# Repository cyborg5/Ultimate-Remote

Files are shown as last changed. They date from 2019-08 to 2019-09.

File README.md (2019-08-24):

# Assistive Technology Ultimate Remote
## This assistive technology device combines infrared and Bluetooth control that can be operated with just 2 or 3 AT switches

In my lifelong struggle to deal with my neuromuscular disease Spinal Muscular Atrophy (SMA), I've built a variety of assistive technology devices. But the most powerful and useful device I've built is my "Ultimate Remote". It combines infrared control of TV, DVR/cable box, DVD/Blu-ray players as well as IR mouse and keyboard emulation. It also includes a Bluetooth device for iOS switch control of my iPhone or iPad. The first version of this device was created in the late 2015 and it has evolved through several versions. It's always been my intent to document the device so that other disabled people can take advantage of what I've developed. Because it was an evolving design I've not documented it until now. However I've cleaned up the code, redesigned the 3D printed enclosure and it's finally ready to share with the world.

This repository contains all of the files will need to build this device.

A complete tutorial on how to build and operate it can be found on the Adafruit Learning System at [https://learn.adafruit.com/building-the-assistive-technology-ultimate-remote/](https://learn.adafruit.com/building-the-assistive-technology-ultimate-remote/) coming soon.

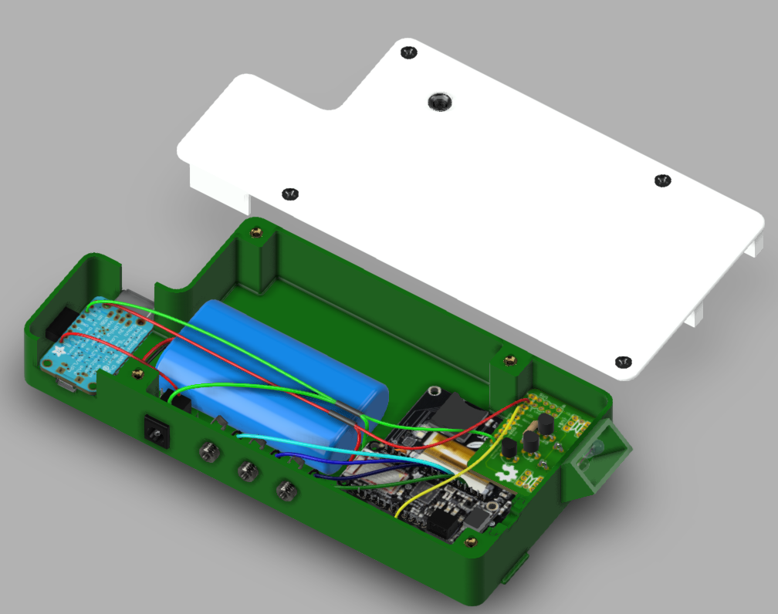
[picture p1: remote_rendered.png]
rendered_image


Included in this repository
 - STL files  -- 3D printer files for the case
    - M3 screws with brass inserts -- files for case held together with M3 screws
      - case_m3.stl
      - lid_with_hole_m3.stl
      - lid_without_hole_m3.stl
    - 6-20 screws into plastic -- files for case held together by #6-20 sheel metal screws
      - case_6-20.stl
      - lid_with_hole_6-20.stl
      - lid_without_hole_6-20.stl
    - dongle_case.stl  --  3D printer file for dongle case
    - dongle_lid.stl  -- 3D printer file for dongle lid
    - door.stl  --  3D printer file for USB cover door
    - guard.stl -- 3D printer file for LED guard
 - ultimate_remote  -- source code for the remote
 - trinket_dongle  -- source code for keyboard and mouse emulator dongle
 - Ultimate Remote 2.3.f3z   -- Fusion 360 model for case and components

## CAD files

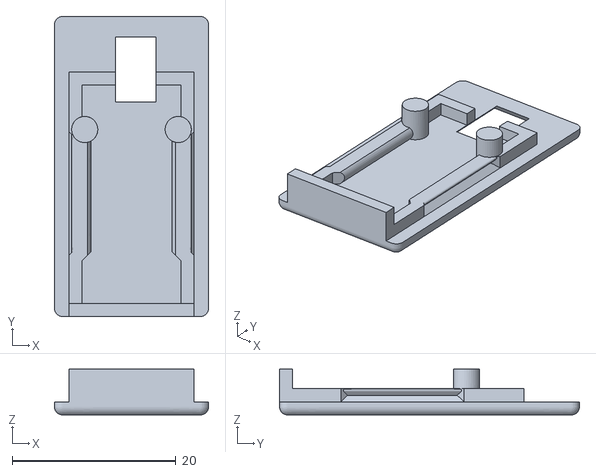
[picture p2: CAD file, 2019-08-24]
STL files/dongle_lid.stl
18.8 x 36.7 x 5.60

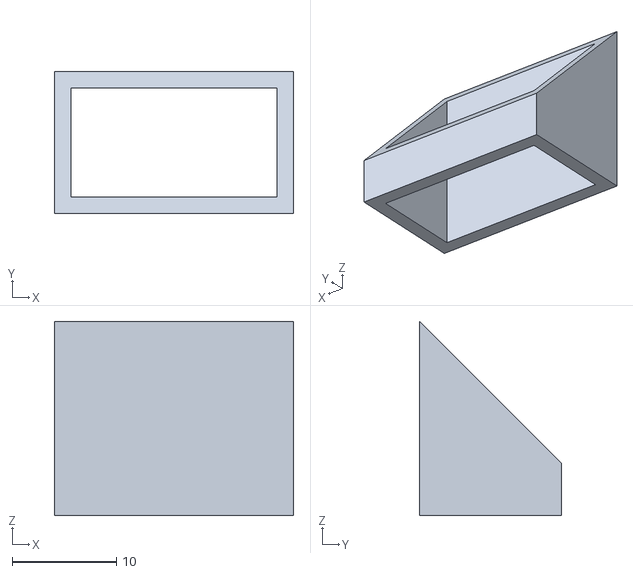
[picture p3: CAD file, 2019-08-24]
STL files/guard.stl
22.9 x 13.6 x 18.6

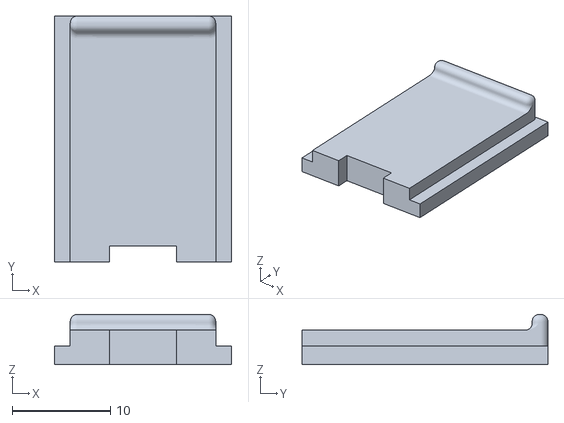
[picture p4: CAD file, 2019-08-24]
STL files/door.stl
18.0 x 25.0 x 5.10

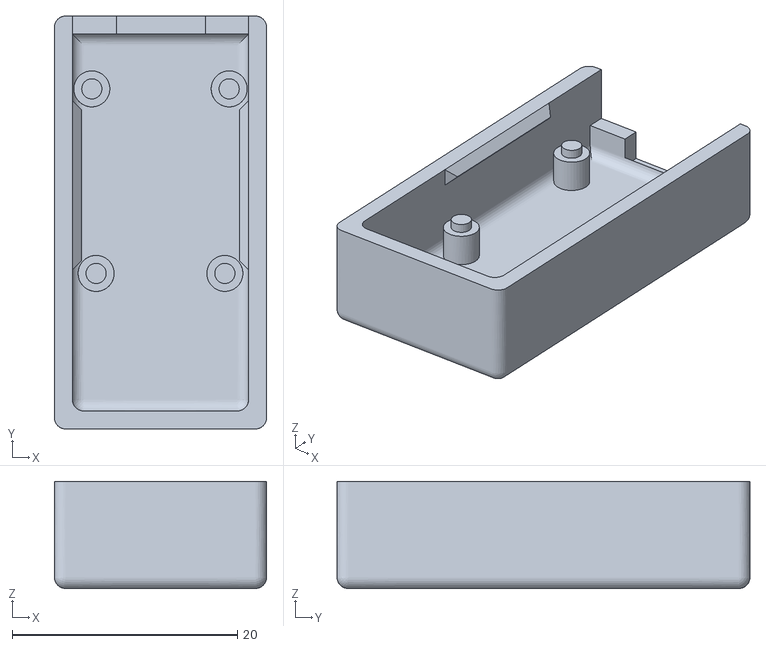
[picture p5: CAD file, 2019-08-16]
STL files/dongle_case.stl
18.8 x 36.7 x 9.50

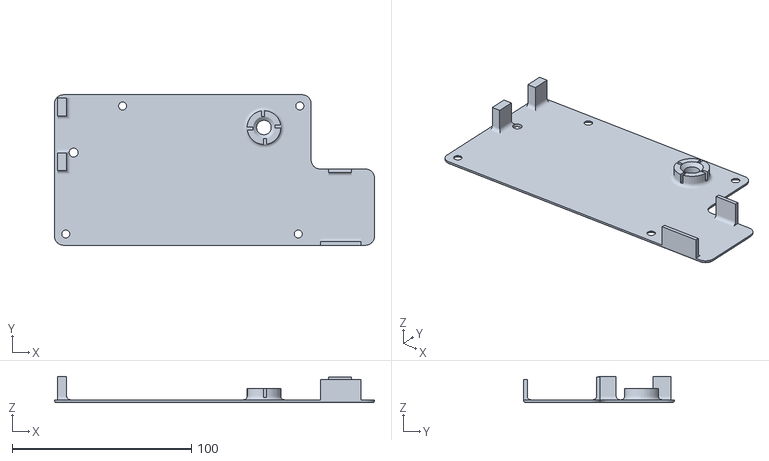
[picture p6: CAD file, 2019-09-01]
STL files/6-20 screws into plastic/lid_with_hole_6-20.stl
178.4 x 84.0 x 14.6

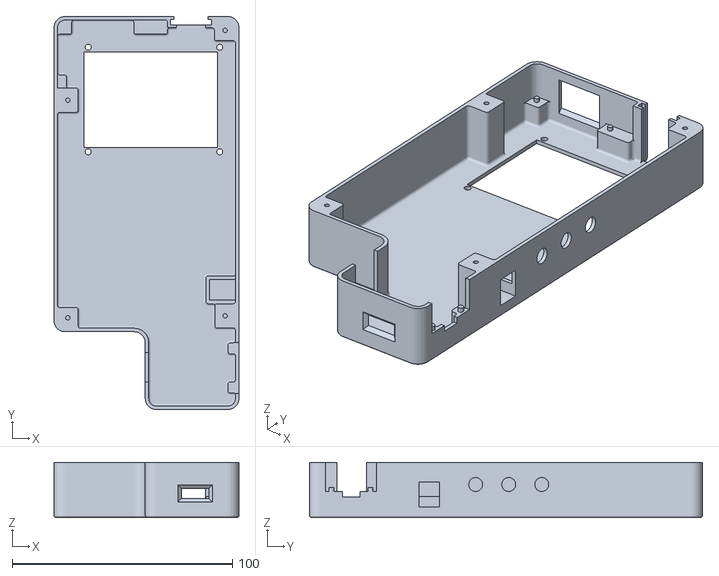
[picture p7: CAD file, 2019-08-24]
STL files/6-20 screws into plastic/case_6-20.stl
84.0 x 178.4 x 25.0

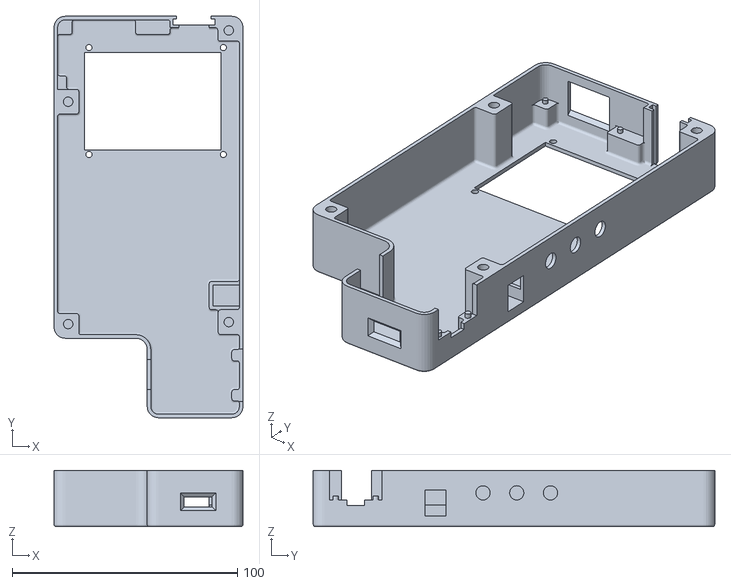
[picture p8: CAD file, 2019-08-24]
STL files/M3 screws with brass inserts/case_m3.stl
84.0 x 178.4 x 25.0

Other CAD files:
STL files/M3 screws with brass inserts/lid_with_hole_m3.stl
STL files/6-20 screws into plastic/lid_without_hole_6-20.stl
STL files/M3 screws with brass inserts/lid_without_hole_m3.stl

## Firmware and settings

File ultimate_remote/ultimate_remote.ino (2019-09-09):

/*
 * Code for "Ultimate Remote" which handles transmission of IR codes for TV, cable, Blu-ray etc.
 * as well as a Bluetooth mode to connect to an iOS device such as iPad or iPhone to use Bluetooth
 * switch control features
 * 
 * Designed for use with 3 switches that are "Left", "Select", and "Right". See "my_inputs.h" for details.
 * 
 * All files in his package are open source under Creative Commons CC BY-SA
 * 
 * Developed by Chris Young cy_borg5@cyborg5.com
 * http://tech.cyborg5.com/
 * 
 */

#define MY_DEBUG 0
#define USE_BLE 1
#define USE_TOUCHSCREEN 1

/***************************
 * Feather TFT
 ***************************/
#include <Wire.h>
#include <Adafruit_ILI9341.h>
//Assumes Feather M0 or M4 or other compatible
   #define STMPE_CS 6
   #define TFT_CS   9
   #define TFT_DC   10
   #define SD_CS    5
#include <Fonts/FreeMono18pt7b.h>
#include "SymbolMono18pt7b.h"
Adafruit_ILI9341 display= Adafruit_ILI9341(TFT_CS, TFT_DC);
#define BACKLIGHT_PIN  13

void Message(const char msg[],uint16_t Duration) {
#if MY_DEBUG
  Serial.println(msg);
#endif
  display.fillRect(0,0,240,50,ILI9341_BLACK); 
  display.setCursor(0,0);
  display.println(msg); 
  delay(Duration);
}

void error(const char err[]) {
  Message(err, 2000);
  //while (1);
}

/***************************
 * Global Variables
 ***************************/

//Row and Col are the current position of the cursor.
//pRow and pCol are the previous position of the cursor.
uint8_t Row, pRow, Col, pCol; 

//The number of rows in the current page.
uint8_t Num_Rows;

//The width of the current page.
uint8_t Page_Width;

//Status of the display backlight. Turns itself off after certain amount of time.
//Also the "select" command doesn't work when the display is off just in case.
bool Backlight_Status;  

//"Page" is the currently displayed page. "Old_Page" remembers what page we were on
// when we switched to Bluetooth mode so that when we exit Bluetooth we will go back to the
// page that we were on.
uint8_t Page, Old_Page;

//Timestamp of the last time we updated the screen i.e. processed a command
uint32_t Time_of_Last_Update;

//The most recent results from Read_Buttons()
uint8_t Current_Buttons;

//Each command consists of a character display, the 32-bit IR value to be
// transmitted, the protocol number, and a special flag hich alternatively may indicate
// the number of bits.
typedef struct cmnd {
  uint8_t Glyph;    //The character to be displayed
  int32_t Value;    //string of bits to be transmitted or page number two change to
                    // if Special == SPL_CHANGE_PAGE
  uint8_t Protocol; //Sony, NEC etc.
  uint8_t Special;  //special handling flag or number of bits
} cmnd_t;

//The current command that the cursor rests on.
struct cmnd Current;

//The full keyboard screen PAGE_KB needs special handling so that it properly displays
// shifted characters. The flag kb_shift is true if we have toggled on Shift.
// This array maps on shifted display glyphs to their shifted value.
bool kb_shift;
uint8_t Shifted [] = {
          0,  1,  2,  3,  4,  5,  6,  7,  8,  9,
         10, 11, 12, 13, 14, 15, 16, 17, 18, 19,
         20, 21, 22, 23, 24, 25, 26, 27, 28, 29,
         //      sp   !   "   #   $   %   &   ' 
         30, 31, 32, 33, 34, 35, 36, 37, 38,'"',
       // (   )   *   +   ,   -   .   /   0   1  
         40, 41, 42, 43,'<','_','>','?',')','!',
       // 2   3   4   5   6   7   8   9   ;   ;  
         '@','#','$','%','^','&','*','(',':',59,
         60, 61, 62, 63, 64, 65, 66, 67, 68, 69,
         70, 71, 72, 73, 74, 75, 76, 77, 78, 79,
         80, 81, 82, 83, 84, 85, 86, 87, 88, 89,
         90,'{','|','}', 94, 95,'~','A','B','C',
        'D','E','F','G','H','I','J','K','L','M',
        'N','O','P','Q','R','S','T','U','V','W',
        'X','Y','Z',123,124,125,126,127};
  
//Types of special commands stored in Current.Special
#define SPL_QUIT    1
#define SPL_REC     2
#define SPL_GOTO_RIGHT 3
#define SPL_GOTO_DOWN 4
#define SPL_GOTO_TVAR 5
#define SPL_CHANGE_PAGE 6
#define SPL_HOLD 7
#define SPL_KB_SHIFT 8

//The maximum number of commands in a display column
#define COL_MAX   14

//The number of minutes of inactivity before the backlight turns off
#define LIGHT_TIMEOUT 5ul

//Return codes from Read_Buttons(). 
#define PUSHED_NONE     0
#define PUSHED_LEFT     1
#define PUSHED_SELECT   2
#define PUSHED_RIGHT    4
#define PUSHED_DOWN     (PUSHED_RIGHT + PUSHED_SELECT)
#define PUSHED_UP       (PUSHED_LEFT  + PUSHED_SELECT)
#define PUSHED_ALL      (PUSHED_LEFT  + PUSHED_SELECT + PUSHED_RIGHT)
//Not used but here just for illustrative purposes
#define PUSHED_SPLIT    (PUSHED_RIGHT + PUSHED_LEFT)

//Specifies the pages of commands to be displayed
#include "my_pages.h"

//Handles touchscreen input
#include "my_touch.h"

//Hardware specific routines to read the buttons
#include "my_inputs.h"

//All of my code for handling BLE switch control
#include "my_ble_code.h"

IRsend mysend; //Infrared sending object

//Turns the backlight on or off depending on flag.
void setBacklight(bool Flag) {
  Backlight_Status = Flag;
  if(Backlight_Status) {
    digitalWrite(BACKLIGHT_PIN, HIGH);
    //Record the time so that we know when to turn off the backlight for being idle too long
    Time_of_Last_Update = millis(); 
  } else {
    #if(MY_DEBUG)
      Serial.println("Backlight off");
    #endif
    digitalWrite(BACKLIGHT_PIN, LOW);    
  }
}

//Displays an "are you sure?" message on the display
// user must press "Right" button for yes. Any other press
// or a timeout results in no.
bool Are_You_Sure() {
  bool Result=false;
  unsigned long Amount = millis();    //Start the timeout clock
  display.fillScreen(ILI9341_BLACK);
  display.setCursor(0, 0); display.print(F("R U sure?"));
  display.setCursor(0, 25); display.print(F("Press Right"));
  display.setCursor(0, 50); display.print(F("For Yes"));
  do {    //Read the buttons until one is pressed for time runs out
    if (Read_Buttons() ) break;
  } while ( (millis() - Amount) < (3000ul) ); //3 second time limit
  display.setCursor(0, 75);
  if (Current_Buttons == PUSHED_DOWN) {
    display.print("Success!");
    Result=true;
  } else {
    display.print("Time Out");
  }
  delay (3000);
  display.fillScreen(ILI9341_BLACK);
  Update_Page();
  return Result; //Returns true if you confirmed yes otherwise false
};

//Handles special circumstances. Returns true if you should not
//do anything else. If false you should go ahead and transmit the code.
bool Do_Special (uint8_t Special) {
  bool Results = false;
  uint32_t Amount;
  switch (Special) {
    case SPL_QUIT:
      //Turn off the backlight and do nothing for 10 seconds
      Results= true;  //This means do not send any code. We've handled it.
      setBacklight(false); //Turn off the backlight
      delay(10000); 
      break;
    case SPL_REC:
      //Ask "Are you sure?" after pressing a record button.
      //The function returns true for yes which means we want to send the code
      Results = (!Are_You_Sure()); 
      Update();   //Redraw the screen to clear the "Are you sure?" message.
      break;
    case SPL_CHANGE_PAGE:
      //Change to a different page or enter Bluetooth mode
      Old_Page = Page;      //Remember where we were so if we exit Bluetooth we can come back
      Page = Current.Value; //The page we are switching to. 
      kb_shift = false;     //Always start with a fresh shift status
      mysend.send(CYKM,CYKM_TOGGLE+CYKM_TOGGLE_RESET,0);//Release all toggles when changing pages
      Update_Page();        //Redraw the entire new page.
      Results = true;       //Don't send any code. We've handled it.
      #if(MY_DEBUG)
        Serial.print("changed page to:"); Serial.println(Page,DEC);
      #endif
      break;
    case SPL_HOLD:
      //Some cable commands require that you hold down the button for an extended
      //period of time. All of these commands are the "SA" protocol so we use
      //Current.Protocol field to specify the number of seconds.
      Amount = millis();
      do {
        mysend.send(SA, Current.Value,0);
        delay(30);
      } while ((millis() - Amount) < (1000ul *Current.Protocol));
      Results = 1;  //We handled it so don't send again.
      break;
    //These three special commands force the cursor to move to a particular 
    // row and column. They still send the command.
    case SPL_GOTO_RIGHT:
      Row = 3; Col = 1; Update();   break;
    case SPL_GOTO_DOWN:
      Row = 3; Col = 3; Update();   break;
    case SPL_GOTO_TVAR:
      Row = 2; Col = 3; Update();   break;
    case SPL_KB_SHIFT:
      //Toggle the shift mode for PAGE_KB
      kb_shift=!kb_shift;
      Update_Page();
      Row = 4; Col = 10; Update();//Remain on the shift command
      break;
  };
  return Results;
};

#define DELTA_R 29
#define DELTA_C 22
#define BASE_C 0
#define BASE_R 22
//Displays the glyph at particular column and row
void Show_Cmd(uint8_t c,uint8_t r) {
  uint16_t fg,bg,Glyph; //Foreground color, background, and character to be displayed
  if ( (r==Row) && (c==Col)) {//This is a cursor
    fg=ILI9341_BLACK;  
    bg=display.color565(255,255,0);
    //To the right of the last column is a pair of virtual columns that allow you to 
    //go up or down a row without having to use chords.
    if(c==(Page_Width+1)) { //Go 2 presses right of the last command and select to go up
      c--;
      Glyph=MY_UP_ARROW;
    } else if(c==Page_Width) { //Go one press right of the last command and select to go down
      Glyph=MY_DOWN_ARROW;
    } else {  //Otherwise display the actual character
      Glyph=MyCommands[Pages[Page][r]][c].Glyph;
      if(kb_shift && (r>0) && (Glyph<127)) {
        Glyph= Shifted [Glyph];
      }
    }
  } else {//Not a cursor
    fg=ILI9341_WHITE; bg=ILI9341_BLACK;
    //If we are in a virtual column, erase the up or down arrow that was temporarily displayed
    //and then draw the proper character in the last column.
    if(c==(Page_Width+1)) c--;
    if(c==Page_Width) {
      Glyph=' ';
    } else {
      Glyph=MyCommands[Pages[Page][r]][c].Glyph;
      if(kb_shift && (r>0) && (r<5) && (Glyph<127)) {
        Glyph= Shifted [Glyph];
      }
    }
  }
  //First draw the background rectangle in the background color
  display.fillRect(DELTA_C*c-1, DELTA_R*r,DELTA_C+1,DELTA_R,bg);
  //Decide which font to use
  if( (Glyph>=32) && (Glyph<=126) ){ //If it's 33-126 then use standard mono 18 font
    display.setFont(&FreeMono18pt7b);
  } else {
    display.setFont(&SymbolMono18pt7b);//Otherwise use special symbol font
    if (Glyph>126) {      //Remap anything above 127 to be in the range 32 and upwards
      Glyph-=(127-32);
    }
  }
  //Draw the actual character glyph
  display.drawChar(BASE_C+c*DELTA_C,BASE_R+r*DELTA_R,Glyph,fg,bg,1);
  display.setFont();//Reset to default font for messages
}

//Draw or redraw the entire page
void Update_Page (void) {
  display.fillScreen(ILI9341_BLACK);
  if (Page == PAGE_BLE) {
    Message("Switch Cntrl.", 1000);
    return;
  }
  Row = 1; Col = 0; pRow=1; pCol=0;
  Num_Rows = Num_Rows_in_Page[Page]; 
  uint8_t i,j;
  for (i = 0; i < Num_Rows; i++) {
    if (i==0) {
      Page_Width = PAGE_BLE+1;
    } else {
      Page_Width = Page_Widths[Page]; //The width of the current page
    }
    for (j =0; j < Page_Width; j++) {
      //delay (1000);
      Show_Cmd(j,i);
    }
  };
  Update();
};

//We've completed a command do some housekeeping
//Update the time of the last command so that we know when to turn 
// the backlight off again.
//
void Update () {
  setBacklight(true);   //Turn on the backlight
  Show_Cmd(pCol,pRow);  //Erase the previous cursor
  Show_Cmd(Col,Row);    //Draw the new cursor
  pRow=Row;pCol=Col;    //Record the cursor current position so we can erase it next time
};

//These next four functions move the cursor Up, Down, Left, or Right and wrap around
// if you go off the edge.
void Do_Up() {
  Row = (Row - 1 + Num_Rows) % Num_Rows; Update ();
};

void Do_Down () {
  ++Row;
  Row = Row % Num_Rows; Update ();
};

void Do_Right () {
  Col = (Col + 1) % (Page_Width+2); Update();
};

void Do_Left () {
  Col = (Col - 1 + Page_Width+2) % (Page_Width+2); Update();
};

//Handle the pressing of the Select button which can have different meanings
//depending on context.
void Do_Select () {
  if(Col==Page_Width) {  //If we are in the first virtual column then go down
    Do_Down();
    delay(300);
    return;
  } else if(Col==(Page_Width+1)) { //If we are in the second virtual column then go up
    Do_Up();
    delay(300);
    return;
  }
  //Pick the current command out of the command table
  Current=MyCommands[Pages[Page][Row]][Col];
#if(MY_DEBUG)
  Serial.print("Page:"); Serial.print(byte(Page));  Serial.print(" Row:"); Serial.print(byte(Row)); Serial.print(" Col:"); Serial.println(byte(Col));
  Serial.print("sent: "); Serial.print(Pnames(Current.Protocol)); Serial.print(" 0x"); Serial.print(Current.Value, HEX);
  Serial.print(" bits:"); Serial.println (Current.Special);
#endif
  uint16_t Bits=0;
  if(Backlight_Status) {//only do select if display active
    //If Do_Special returns true then we don't need to do anything else
    if (Do_Special(Current.Special)) {
      return;
    }
    //SONY protocol has different number of bits but it's easier to calculate them than to
    //specify them in the table.
    if (Current.Protocol== SONY) {
      if(Current.Value>0x7fff) Bits= 20; else Bits= 15;
    } else {
      if (Current.Protocol== SAMSUNG36) {
        //Although this is called "Bits" is actually the address portion of a 36 bit protocol.
        //Fortunately the address doesn't vary between commands for this device. I only have one
        // device that uses this protocol.
        Bits=0x400; 
      }
    }
    if(Current.Protocol==RC6) {
      //For this protocol we need to specify the number of bits in the Current.Special field.
      //This means that we can't use special commands with this protocol and the number of
      // types of special commands cannot exceed 19 because there is a 20-bit protocol option here.
      Bits= Current.Special;
    }
    //If the keyboard shift is on and this is a keyboard command then add in the shift parameter
    if (kb_shift && (Current.Protocol==CYKM)) {
      Current.Value |= CYKM_SHIFT;
    }
    //Actually send the IR command
    mysend.send(Current.Protocol, Current.Value, Bits);
    Update();
  } else { //If backlight is off, turn it back on and refresh the page but don't process "Select".
    Update_Page();
  }
};

//Initialize everything
void setup() {
  #if(MY_DEBUG)
    while (! Serial) {}; delay (500);
    Serial.begin(9600); Serial.println("testing 123");
  #endif
  Initialize_Buttons(); //This function defined in my_inputs.h
  pinMode (BACKLIGHT_PIN, OUTPUT); //Backlight connected to pin 13
  display.begin();
  display.setRotation(1);
  display.setCursor(0, 0);
  display.setTextSize(3); //Default font size for messages
  display.setTextColor(ILI9341_WHITE);
  display.fillRect(0,0,240,320,ILI9341_BLACK); 
  Initialize_Touch();   //Defined in my_touch.h
  Initialize_BLE();
  Message("Updated 2019-09-09", 5000);
  setBacklight(true);
  //Start out on the cable page
  Page = PAGE_CBL; 
  kb_shift=false;
  Update_Page();
}

void loop() {
  if(Read_Buttons()) {
    setBacklight(true);
    //If buttons were pressed and you are in BLE mode, handle BLE mode.
    if (Page == PAGE_BLE) {
      switch (Current_Buttons) {
        case PUSHED_LEFT:   
          Message("LEFT",0);    
          send_BLE_KeyCode('l'); 
          break;
        case PUSHED_SELECT: 
          Message("SELECT",0);  
          send_BLE_KeyCode('s'); 
          break;
        case PUSHED_RIGHT:  
          Message("RIGHT",0);   
          send_BLE_KeyCode('r');  
          break;
        case PUSHED_ALL:
          exitBLE();  //Change back to IR mode
          break; 
      }
    } else {
      //If buttons were pressed and you are in IR mode, handle cursor and select commands
      #define ARROW_SPEED 150
      switch(Current_Buttons) {
        case PUSHED_RIGHT:  
          Do_Right();   delay(ARROW_SPEED); 
          break;
        case PUSHED_LEFT:   
          Do_Left();    delay(ARROW_SPEED); 
          break;
        case PUSHED_SELECT: 
          Do_Select();  delay(0); 
          break;
        case PUSHED_UP:     
          Do_Up();      delay(ARROW_SPEED + 200);
          break;
        case PUSHED_DOWN:   
          Do_Down();    delay(ARROW_SPEED + 200);
          break;
      };
    };
  };
  //If it's been too long since we processed a command, then turn off the backlight.
  //Any call to Update() will reset the timer.
  if (Backlight_Status){
    if ((millis()-Time_of_Last_Update)>(LIGHT_TIMEOUT*60ul*1000ul)) {
      setBacklight(false);//Blank display after certain number of minutes.
    }
  };
};

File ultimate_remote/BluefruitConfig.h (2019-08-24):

// COMMON SETTINGS
// ----------------------------------------------------------------------------------------------
// These settings are used in both SW UART, HW UART and SPI mode
// ----------------------------------------------------------------------------------------------
#define BUFSIZE                        128   // Size of the read buffer for incoming data
#define VERBOSE_MODE                   false  // If set to 'true' enables debug output
/*

// SOFTWARE UART SETTINGS
// ----------------------------------------------------------------------------------------------
// The following macros declare the pins that will be used for 'SW' serial.
// You should use this option if you are connecting the UART Friend to an UNO
// ----------------------------------------------------------------------------------------------
#define BLUEFRUIT_SWUART_RXD_PIN       9    // Required for software serial!
#define BLUEFRUIT_SWUART_TXD_PIN       10   // Required for software serial!
#define BLUEFRUIT_UART_CTS_PIN         11   // Required for software serial!
#define BLUEFRUIT_UART_RTS_PIN         -1   // Optional, set to -1 if unused


// HARDWARE UART SETTINGS
// ----------------------------------------------------------------------------------------------
// The following macros declare the HW serial port you are using. Uncomment
// this line if you are connecting the BLE to Leonardo/Micro or Flora
// ----------------------------------------------------------------------------------------------
#ifdef Serial1    // this makes it not complain on compilation if there's no Serial1
  #define BLUEFRUIT_HWSERIAL_NAME      Serial1
#endif


// SHARED UART SETTINGS
// ----------------------------------------------------------------------------------------------
// The following sets the optional Mode pin, its recommended but not required
// ----------------------------------------------------------------------------------------------
#define BLUEFRUIT_UART_MODE_PIN        12    // Set to -1 if unused

*/
// HARDWARE SPI SETTINGS
// ----------------------------------------------------------------------------------------------
// The following macros declare the pins to use for HW SPI communication.
// SCK, MISO and MOSI should be connected to the HW SPI pins on the Uno, etc.
// This should be used with nRF51822 based Bluefruit LE modules that use SPI.
// ----------------------------------------------------------------------------------------------
#define BLUEFRUIT_SPI_CS               8
#define BLUEFRUIT_SPI_IRQ              7
#define BLUEFRUIT_SPI_RST              4    // Optional but recommended, set to -1 if unused

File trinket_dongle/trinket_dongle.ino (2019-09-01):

#include <IRLibRecv.h>
#include <IRLibDecodeBase.h>
#include <IRLib_P12_CYKM.h>

#define MY_DEBUG 0
IRrecv My_Receiver(3); //trinket

IRdecodeCYKM My_Decoder;
uint16_t myBuffer[RECV_BUF_LENGTH];

bool Unit_Active;
uint32_t time, diff;

void setup() {
  #if(MY_DEBUG)
    Serial.begin(9600);
    while (! Serial) {};
    Serial.println("Trinket Dongle Working");
  #endif
  Mouse.begin();
  Keyboard.begin();
  My_Receiver.enableIRIn(); // Start the receiver
  My_Decoder.mouseSpeed=10;
  My_Receiver.enableAutoResume(myBuffer);
  Unit_Active=true;  time=millis(); 
}

#define HOLD_TIMEOUT 2ul //Release toggle after two minutes
void loop() {
  if (Unit_Active){
    diff=millis()-time;
    if (diff>(HOLD_TIMEOUT*60ul*1000ul)){
      Unit_Active=false; 
      My_Decoder.doMouseKeyboard(CYKM_TOGGLE+CYKM_TOGGLE_RESET);
      My_Decoder.mouseSpeed=10;
    }
  };
  if (My_Receiver.getResults()) {
    if(My_Decoder.decode()) {
      My_Decoder.doMouseKeyboard();
      #if(MY_DEBUG)
        My_Decoder.dumpResults();
      #endif
      Unit_Active=true;  time=millis(); 
    }
    My_Receiver.enableIRIn(); 
  }
}

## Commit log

2019-08-16 initial commit of STL
    initial commit of STL
    [case_6-20.stl, case_m3.stl, dongle case.stl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]
2019-08-16 replace proper file
    [dongle case.stl, dongle_case.stl]
2019-08-24 Initial upload
    Presently.
    [case_6-20.stl, case_m3.stl, dongle_lid.stl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]
2019-08-31 Various updates
    [lid_with_hole_6-20.stl, lid_with_hole_m3.stl, lid_without_hole_6-20.stl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]
2019-09-01 Updated STL files
    [lid_with_hole_6-20.stl, lid_with_hole_m3.stl, lid_without_hole_6-20.stl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]
2019-09-09 Fixed are you sure and BLE exit
    [my_inputs.h, ultimate_remote.ino]
